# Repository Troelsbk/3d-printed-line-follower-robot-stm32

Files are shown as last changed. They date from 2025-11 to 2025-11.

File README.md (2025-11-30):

# Line Follower Robot — 3D Printed, Embedded Control System

[]()
[]()
[]()
[]()
[]()
[]()

This repository contains the design files, embedded firmware, and hardware documentation for a compact, custom build  follower robot.  The system is built around a custom 3D-printed chassis, IR reflectance sensors, and dual DC motors driven through an L293D H-bridge. Control logic is implemented using a non-blocking state machine running on an STM32F042 microcontroller.  

---

## System Overview
This project presents a fully self-designed mobile robot engineered to follow a black line on the floor. The platform combines custom 3D-printed mechanics with sensor-driven motor control to achieve reliable autonomous navigation.

<p align="center">
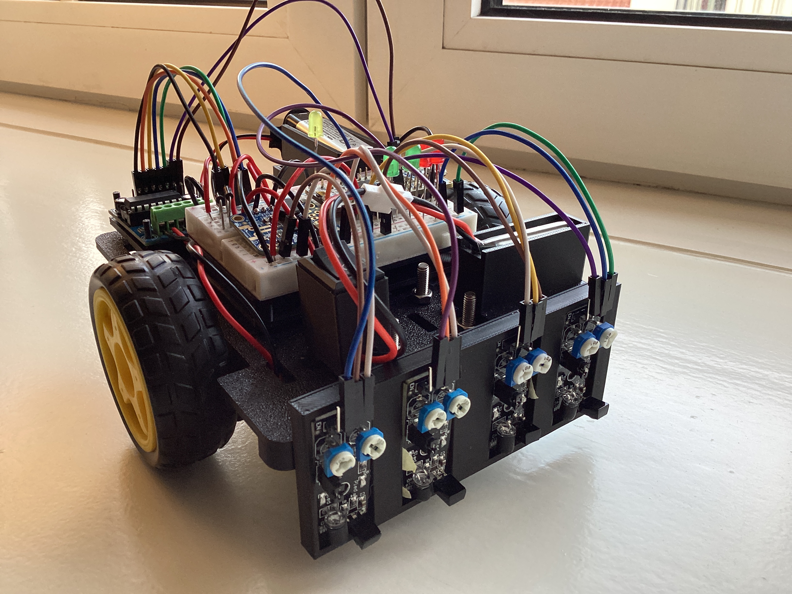
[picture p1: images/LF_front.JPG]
  
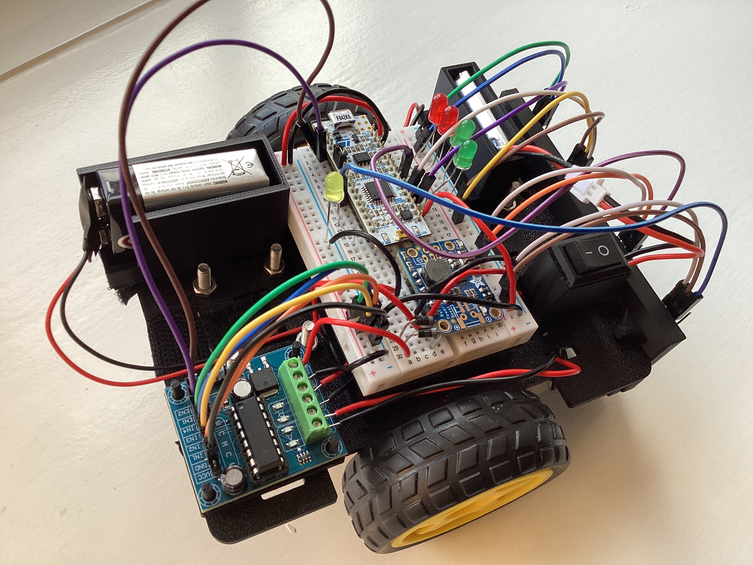
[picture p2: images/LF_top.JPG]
  
</p>

---

## Mechanical Design
A basic 3D-printed chassis was designed in [FreeCAD](https://www.freecad.org/).  
In addition, several smaller components were created to mount the batteries, motor driver, breadboard, on/off switch, and sensors.

<p align="center">
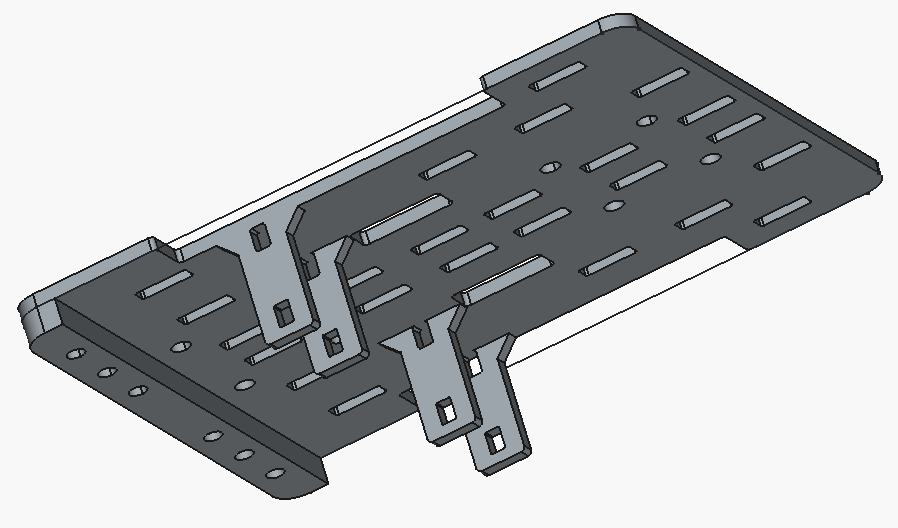
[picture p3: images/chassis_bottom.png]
  
</p>

All design files are available as FreeCAD models in the [FreeCAD](FreeCAD/) folder.

---
## Motors and Motor Driver
The propulsion system consists of standard brushed TT-motors driven using a 50 Hz PWM signal at an operating voltage of approximately 7 V.  
Motor actuation is handled by a pre-assembled L293D H-bridge module.

<p align="center">
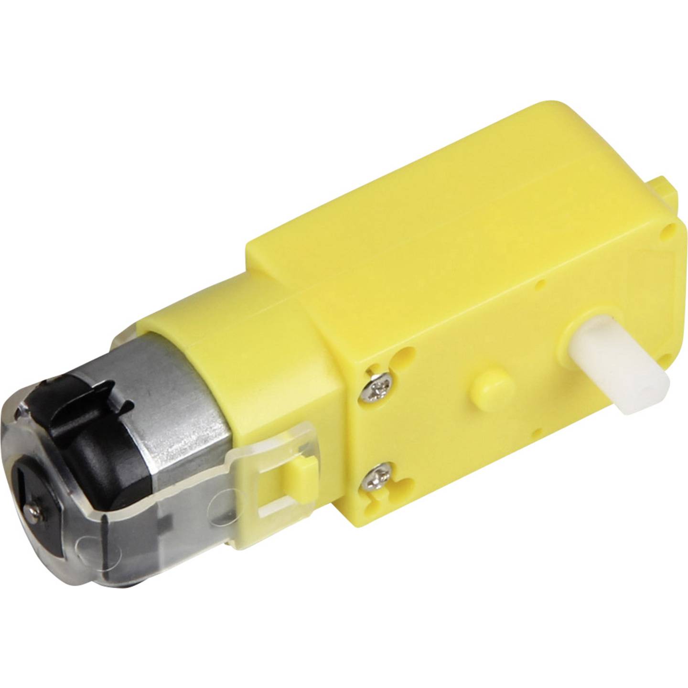
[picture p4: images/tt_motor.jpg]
  

</p>

---

## Sensor System
The robot uses four KY-032 digital infrared proximity sensors for line detection.  
Each sensor provides a binary output indicating whether the reflective surface beneath it corresponds to the track or the background.

The two inner sensors form the primary feedback loop for maintaining a straight trajectory by providing high-resolution deviation information near the center of the line.  
The two outer sensors extend the detection range, enabling early identification of sharp curves and allowing the control logic to initiate more aggressive corrective turns.

---
## Power System
The motor subsystem is supplied by a 9 V battery, with the voltage reduced to approximately 7 V using two series-connected 1N4001 silicon diodes.  
This approach provides a simple fixed-voltage drop suited for brushed DC motors, where load-dependent variations are acceptable.

The microcontroller subsystem is powered by a 3.7 V, 400 mAh LiPo cell.  
Its output is regulated to a stable 5 V using a pre-assembled DC-DC boost converter, ensuring consistent logic-level supply and isolation from motor-induced voltage fluctuations.

---

## Electronics and Circuit Integration
The complete electronic system integrates the microcontroller, sensor array, and power distribution network.  
A detailed schematic of the control electronics is shown below:

<p align="center">
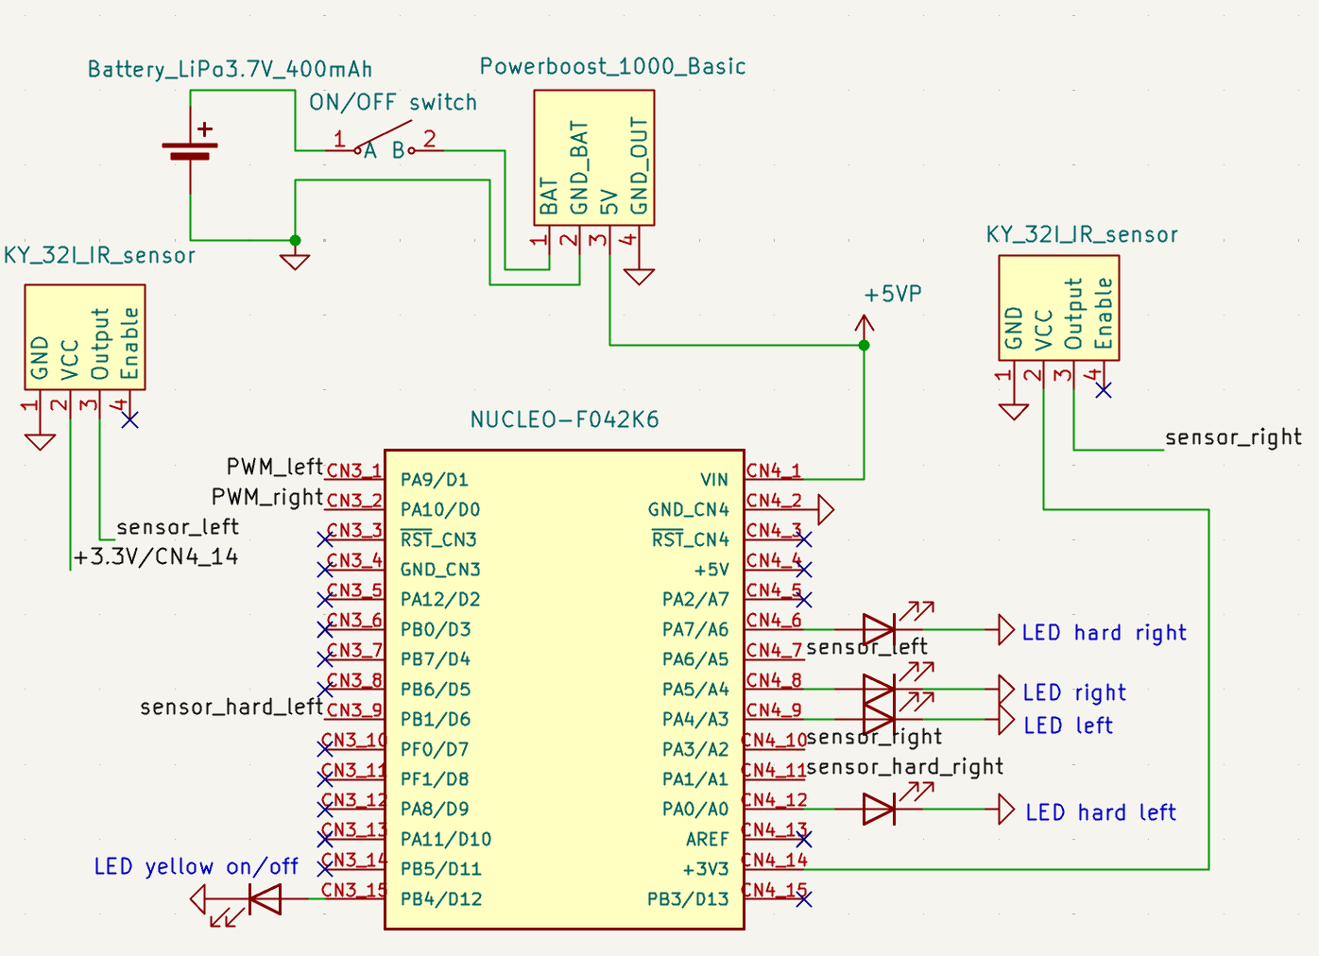
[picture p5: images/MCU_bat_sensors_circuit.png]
  
</p>

The motor power stage, including the voltage-drop diodes and H-bridge driver connections, is illustrated in the following schematic:

<p align="center">
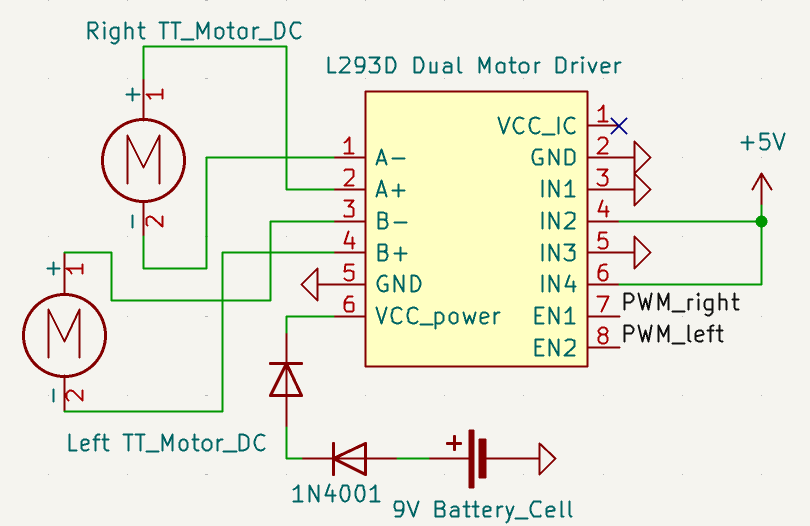
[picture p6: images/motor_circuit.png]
  
</p>

---

## Control Logic
An STM32 Nucleo-F042K6 development board was used as the main controller for this project.  
Motor actuation was implemented as a non-blocking state machine to ensure deterministic PWM updates and responsive sensor handling under all operating conditions.

The high-level control behavior is modeled as a finite state machine, illustrated below:

<p align="center">
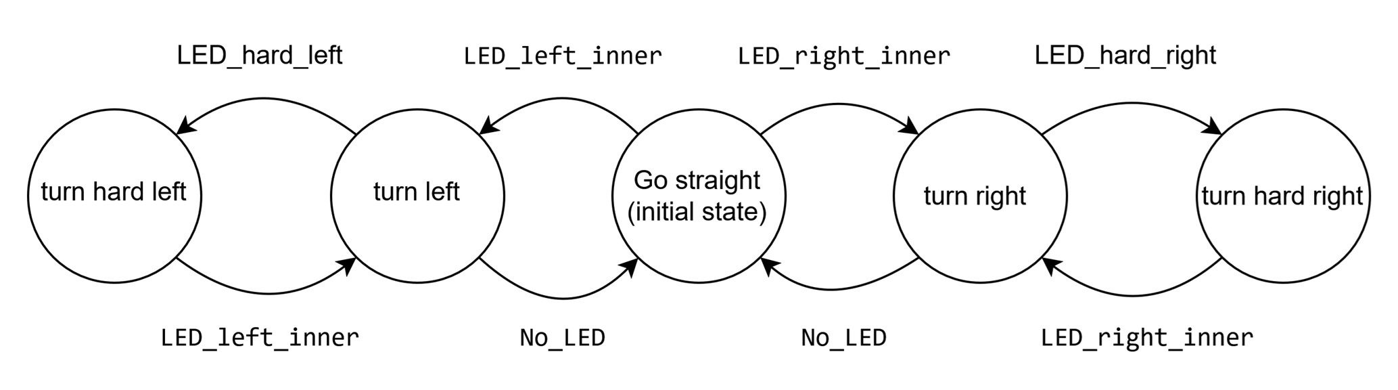
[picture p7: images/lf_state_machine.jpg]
  
</p>

The LED indicators were arranged such that only one LED could be active at any given time, providing a direct visual representation of the current control state.

On the microcontroller, the state machine is represented using an enumeration structure, shown below:

<p align="center">
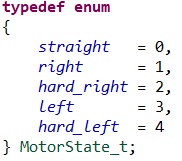
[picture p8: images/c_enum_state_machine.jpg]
  
</p>

State transitions are driven by the sensor-evaluation function, which maps the four digital IR sensor inputs to the appropriate motor-control state:

<p align="center">
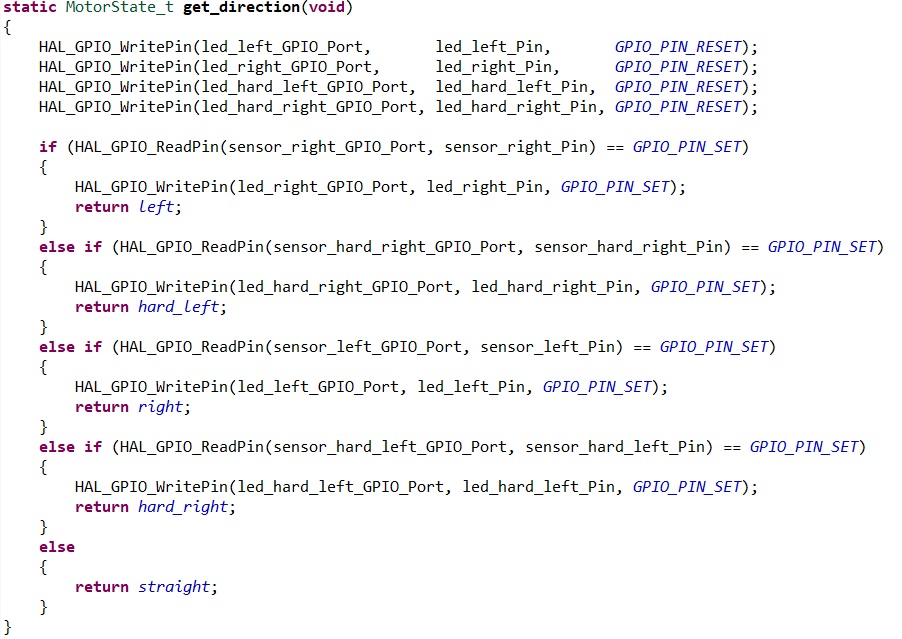
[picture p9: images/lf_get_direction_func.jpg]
  
</p>

The specific PWM duty cycles for each turning mode were determined empirically through iterative testing to achieve smooth and stable motion.

The complete firmware implementation is available in the [Firmware](Firmware/) directory.

---

## Demonstration
A demonstration of the robot’s behavior and line-following performance is provided below:
Demo Video (https://youtu.be/P4spWUcDwMc)

## Conclusion
The line follower robot performed as expected, but several limitations became apparent during testing.  
The absence of closed-loop feedback, combined with the low-quality TT motors, significantly affected control accuracy.  
Without proper PID regulation, the system exhibited noticeable overshoot during initial PWM tuning, and the motors did not provide sufficient torque for precise high-speed maneuvers.

Despite these limitations, the project successfully demonstrated the core functionality of a sensor-driven line follower and provided valuable insight into motor control, embedded implementation, and mechanical design considerations.

## Future Work
Several extensions and improvements could be explored in future iterations of the project:

- Implementing closed-loop PID control to achieve more stable and responsive motor behavior  
- Replacing the microcontroller with an FPGA to evaluate hardware-accelerated control logic  
- Developing a fully analog implementation of the control system and sensor interface as an alternative design approach

---

## License
This project is released under the MIT License.  
See `LICENSE` for details.

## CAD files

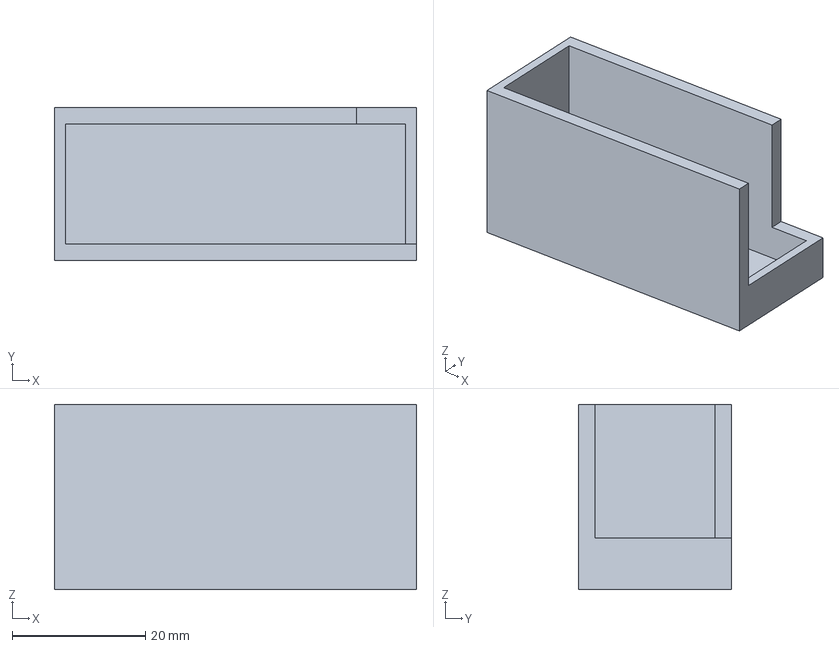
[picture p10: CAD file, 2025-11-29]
FreeCAD/9_volt_bat_mount.FCStd
54.2 x 23.0 x 27.8 mm

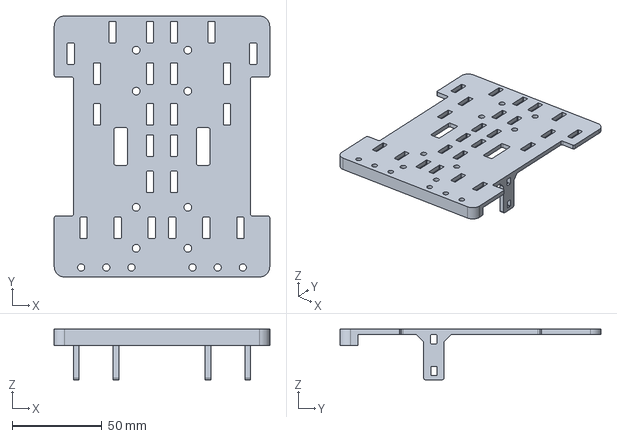
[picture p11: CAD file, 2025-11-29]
FreeCAD/LF_chassis.FCStd
120.0 x 145.3 x 28.2 mm

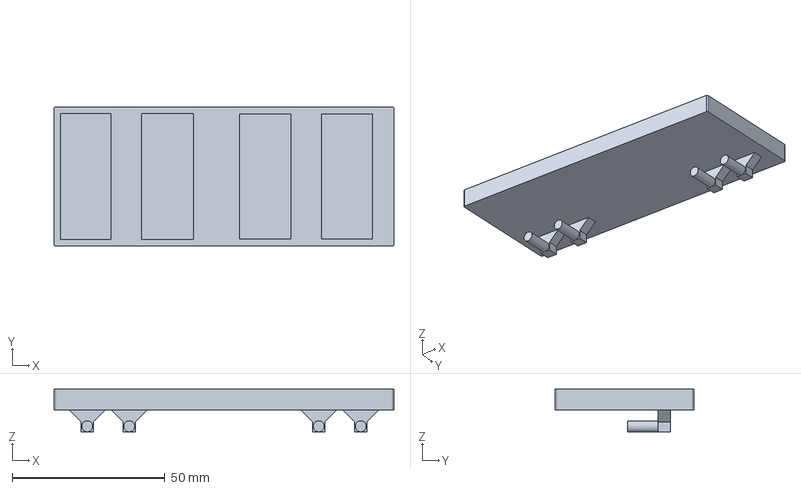
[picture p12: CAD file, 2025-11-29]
FreeCAD/quad_sensor_mount.FCStd
111.3 x 45.6 x 14.0 mm

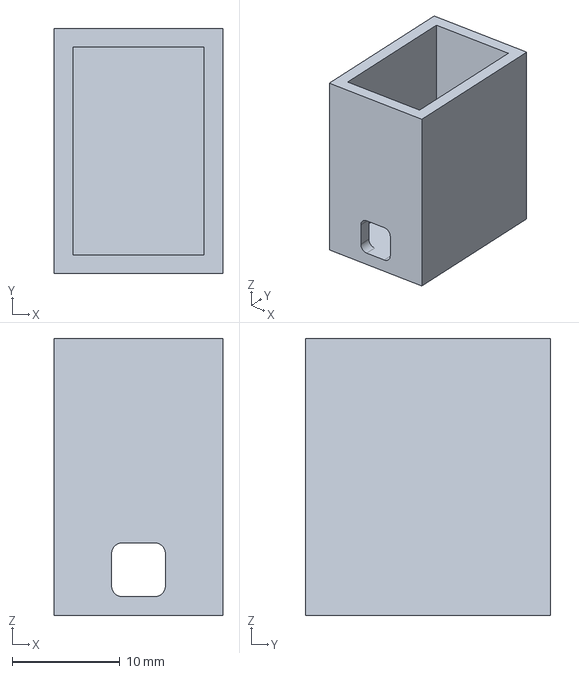
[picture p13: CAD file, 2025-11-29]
FreeCAD/on_off_button.FCStd
15.7 x 22.8 x 25.8 mm

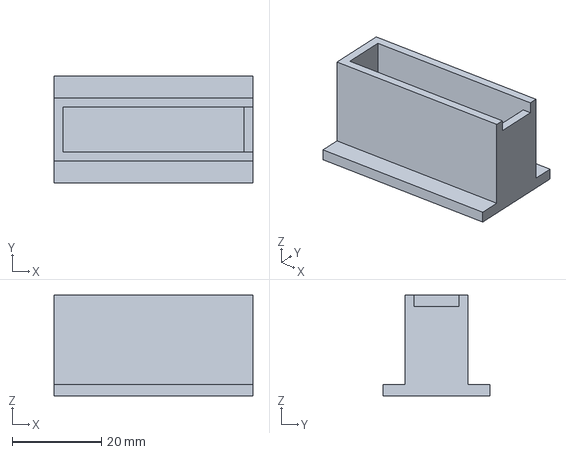
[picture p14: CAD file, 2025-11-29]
FreeCAD/battery_mount.FCStd
44.5 x 24.0 x 22.5 mm

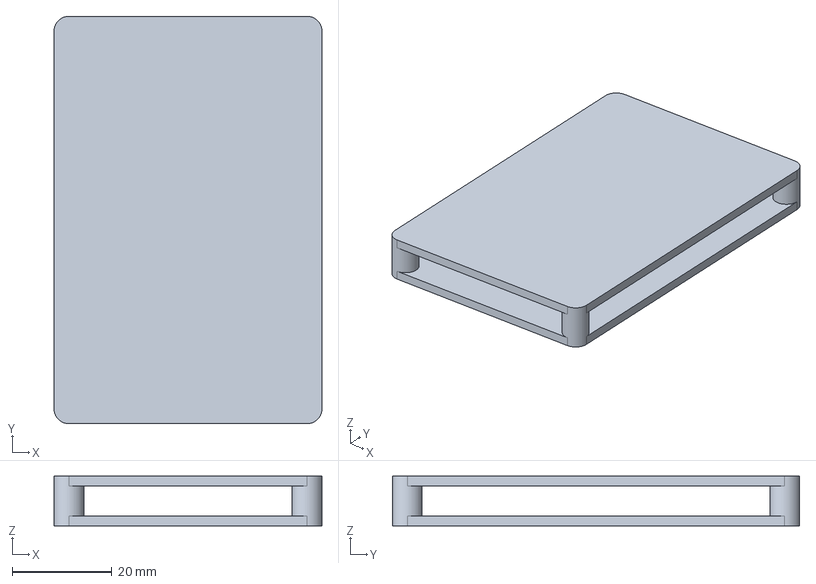
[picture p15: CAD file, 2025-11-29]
FreeCAD/breadboard_mount.FCStd
53.8 x 81.8 x 10.0 mm

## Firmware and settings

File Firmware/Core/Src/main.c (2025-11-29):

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
/* Includes ------------------------------------------------------------------*/
#include "main.h"

/* USER CODE BEGIN PD */
# define left_ch TIM_CHANNEL_2
# define right_ch TIM_CHANNEL_3
/* USER CODE END PD */

TIM_HandleTypeDef htim1;

UART_HandleTypeDef huart2;

/* USER CODE BEGIN PV */
typedef enum
{
    straight   = 0,
    right      = 1,
    hard_right = 2,
    left       = 3,
    hard_left  = 4
} MotorState_t;

typedef struct
{
    uint8_t left_base;
    uint8_t right_base;

    uint8_t left_slow;
    uint8_t right_slow;

    uint8_t left_extra_slow;
    uint8_t right_extra_slow;

    uint8_t left_fast;
    uint8_t right_fast;

    uint8_t left_boost;
    uint8_t right_boost;
} MotorPwm_t;

/* USER CODE END PV */

void SystemClock_Config(void);
static void MX_GPIO_Init(void);
static void MX_USART2_UART_Init(void);
static void MX_TIM1_Init(void);
/* USER CODE BEGIN 0 */
static MotorState_t get_direction(void)
{
    /* all LEDs off */
    HAL_GPIO_WritePin(led_left_GPIO_Port,       led_left_Pin,       GPIO_PIN_RESET);
    HAL_GPIO_WritePin(led_right_GPIO_Port,      led_right_Pin,      GPIO_PIN_RESET);
    HAL_GPIO_WritePin(led_hard_left_GPIO_Port,  led_hard_left_Pin,  GPIO_PIN_RESET);
    HAL_GPIO_WritePin(led_hard_right_GPIO_Port, led_hard_right_Pin, GPIO_PIN_RESET);

    if (HAL_GPIO_ReadPin(sensor_right_GPIO_Port, sensor_right_Pin) == GPIO_PIN_SET)
    {
        //HAL_GPIO_WritePin(led_right_GPIO_Port, led_right_Pin, GPIO_PIN_SET);
        return left;
    }
    else if (HAL_GPIO_ReadPin(sensor_hard_right_GPIO_Port, sensor_hard_right_Pin) == GPIO_PIN_SET)
    {
    	//HAL_GPIO_WritePin(led_hard_right_GPIO_Port, led_hard_right_Pin, GPIO_PIN_SET);
        return hard_left;
    }
    else if (HAL_GPIO_ReadPin(sensor_left_GPIO_Port, sensor_left_Pin) == GPIO_PIN_SET)
    {
    	//HAL_GPIO_WritePin(led_left_GPIO_Port, led_left_Pin, GPIO_PIN_SET);
        return right;
    }
    else if (HAL_GPIO_ReadPin(sensor_hard_left_GPIO_Port, sensor_hard_left_Pin) == GPIO_PIN_SET)
    {
    	//HAL_GPIO_WritePin(led_hard_left_GPIO_Port, led_hard_left_Pin, GPIO_PIN_SET);
        return hard_right;
    }
    else
    {
        /* straight: all LEDs stay off */
        return straight;
    }
}

static void apply_motor_pwm(MotorState_t state, const MotorPwm_t *pwm)
{
    switch (state)
    {
        case straight:
            __HAL_TIM_SET_COMPARE(&htim1, left_ch,  pwm->left_base);
            __HAL_TIM_SET_COMPARE(&htim1, right_ch, pwm->right_base);
            break;

        case left:
            __HAL_TIM_SET_COMPARE(&htim1, left_ch,  pwm->left_slow);
            __HAL_TIM_SET_COMPARE(&htim1, right_ch, pwm->right_fast);
            break;

        case right:
            __HAL_TIM_SET_COMPARE(&htim1, left_ch,  pwm->left_fast);
            __HAL_TIM_SET_COMPARE(&htim1, right_ch, pwm->right_slow);
            break;

        case hard_left:
            __HAL_TIM_SET_COMPARE(&htim1, left_ch,  pwm->left_extra_slow);
            __HAL_TIM_SET_COMPARE(&htim1, right_ch, pwm->right_boost);
            break;

        case hard_right:
            __HAL_TIM_SET_COMPARE(&htim1, left_ch,  pwm->left_boost);
            __HAL_TIM_SET_COMPARE(&htim1, right_ch, pwm->right_extra_slow);
            break;

        default:
            break;
    }
}

// 5 volt settings
//MotorPwm_t pwm = {
//	  .left_base = 			55,
//	  .right_base = 		42,
//	  .left_slow = 			45, // -10
//	  .right_slow = 		32, // -10
//	  .left_extra_slow = 	20, // -35
//	  .right_extra_slow = 	7, // -35
//	  .left_fast = 			65, // +10
//	  .right_fast = 		52, // +10
//	  .left_boost = 		90, // base +35
//	  .right_boost = 		77 // base + 35
//};

/* USER CODE END 0 */

/**
  * @brief  The application entry point.
  * @retval int
  */
int main(void)
{

  /* MCU Configuration--------------------------------------------------------*/

  /* Reset of all peripherals, Initializes the Flash interface and the Systick. */
  HAL_Init();

  /* Configure the system clock */
  SystemClock_Config();

  /* Initialize all configured peripherals */
  MX_GPIO_Init();
  MX_USART2_UART_Init();
  MX_TIM1_Init();
  /* USER CODE BEGIN 2 */
  HAL_TIM_PWM_Start(&htim1, left_ch);
  HAL_TIM_PWM_Start(&htim1, right_ch);

  MotorPwm_t pwm = {
	  .left_base = 			55,
	  .right_base = 		42,
	  .left_slow = 			45, // -10
	  .right_slow = 		32, // -10
	  .left_extra_slow = 	20, // -25
	  .right_extra_slow = 	7, // -25
	  .left_fast = 			65, // +10
	  .right_fast = 		52, // +10
	  .left_boost = 		90, // base +25
	  .right_boost = 		77 // base + 25
  };


  	MotorState_t state = straight;

    const uint32_t control_period_ms = 2U;    /* motor update rate   */
    const uint32_t blink_period_ms   = 100U;  /* PB4 blink period    */

    uint32_t last_control_ms = 0U;
    uint32_t last_blink_ms   = 0U;

  /* USER CODE END 2 */

  /* Infinite loop */
  /* USER CODE BEGIN WHILE */
  while (1)
  {
    /* USER CODE END WHILE */

    /* USER CODE BEGIN 3 */
      uint32_t now = HAL_GetTick();


      if ((now - last_control_ms) >= control_period_ms)
      {
          state = get_direction();
          apply_motor_pwm(state, &pwm);
          last_control_ms = now;
      }


      if ((now - last_blink_ms) >= blink_period_ms)
      {
          HAL_GPIO_TogglePin(GPIOB, GPIO_PIN_4);
          last_blink_ms = now;
      }
  }//while(1) end
  /* USER CODE END 3 */
}

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


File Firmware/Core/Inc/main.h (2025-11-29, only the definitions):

#define MCO_Pin GPIO_PIN_0
#define MCO_GPIO_Port GPIOF
#define led_hard_left_Pin GPIO_PIN_0
#define led_hard_left_GPIO_Port GPIOA
#define sensor_hard_right_Pin GPIO_PIN_1
#define sensor_hard_right_GPIO_Port GPIOA
#define VCP_TX_Pin GPIO_PIN_2
#define VCP_TX_GPIO_Port GPIOA
#define sensor_right_Pin GPIO_PIN_3
#define sensor_right_GPIO_Port GPIOA
#define led_left_Pin GPIO_PIN_4
#define led_left_GPIO_Port GPIOA
#define led_right_Pin GPIO_PIN_5
#define led_right_GPIO_Port GPIOA
#define sensor_left_Pin GPIO_PIN_6
#define sensor_left_GPIO_Port GPIOA
#define led_hard_right_Pin GPIO_PIN_7
#define led_hard_right_GPIO_Port GPIOA
#define sensor_hard_left_Pin GPIO_PIN_1
#define sensor_hard_left_GPIO_Port GPIOB
#define pwm_left_Pin GPIO_PIN_9
#define pwm_left_GPIO_Port GPIOA
#define pwm_right_Pin GPIO_PIN_10
#define pwm_right_GPIO_Port GPIOA
#define SWDIO_Pin GPIO_PIN_13
#define SWDIO_GPIO_Port GPIOA
#define SWCLK_Pin GPIO_PIN_14
#define SWCLK_GPIO_Port GPIOA
#define VCP_RX_Pin GPIO_PIN_15
#define VCP_RX_GPIO_Port GPIOA
#define yellow_led_Pin GPIO_PIN_4
#define yellow_led_GPIO_Port GPIOB

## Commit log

2025-08-26 Add new project folders
    [line_follower.kicad_pcb, line_follower.kicad_sch]
2025-11-29 KiCad update
    [KiCad.kicad_sch, line_follower.kicad_pcb, line_follower.kicad_sch]
2025-11-29 Added images of chassis
    [9_volt_bat_mount.FCStd, LF_chassis.FCStd, battery_mount.FCStd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]
2025-11-29 Added images
    [KiCad.kicad_sch]
2025-11-29 Added stm32 files
2025-11-29 Added additional stm32 files

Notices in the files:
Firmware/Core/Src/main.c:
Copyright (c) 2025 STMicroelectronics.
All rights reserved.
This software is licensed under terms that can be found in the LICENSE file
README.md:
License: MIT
